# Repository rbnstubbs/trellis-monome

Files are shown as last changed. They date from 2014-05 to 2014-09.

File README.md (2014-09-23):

trellis-monome
==============
NOTE: Code is still not optimized for row/col commands! WIP

A monome clone using the Adafruit Trellis keypads

This project was largely based on the Arduinome by Owen Vallis & 
Jordan Hochenbaum: http://flipmu.com/work/arduinome/

Many thanks to Brian Crabtree and Kelli Cain as well as the rest of the monome community for creating supporting open source hardware/software: http://monome.org/

Robin Stubbs - robin.stubbs@uleth.ca

Click "Download ZIP" to get all files ------------------->

***
This program is free software; you can redistribute it and/or modify it under the terms of the GNU General Public License as published by the Free Software Foundation; either version 2 of the License, or (at your option) any later version.

This program is distributed in the hope that it will be useful, but WITHOUT ANY WARRANTY; without even the implied warranty of MERCHANTABILITY or FITNESS FOR A PARTICULAR PURPOSE.  See the GNU General Public License for more details.
***

NOTE: For now you will need Cycling '74 's Max (http://cycling74.com/downloads/), but only the runtime version (free!) in order to run the monomecereal.maxpat

INSTRUCTIONS:

1. Set up Trellis keypads according to adafruit: https://learn.adafruit.com/adafruit-trellis-diy-open-source-led-keypad?view=all

2. Place the Trellis_XY library by George Kuetemeyer in your libraries folder. Test your Trellis keypads using the test sketches - ensure that all LEDs are lighting up in order. If they are jumping from one keypad to another, change the order of addresses under trellis.begin()

3. Upload the latest trellis-monome firmware to your arduino. Start monomecereal.maxpat and choose your serial port (it will be the same as the one you used in the Arduino IDE). Click 'serial on' and 'osc on'

4. Open trellis-monome test.maxpatch and press your keys. Watch the buttons light up! If the right buttons are not lighting check the cable orientation in monomecereal.maxpat

5. You are done! download apps for the monome at http://monome.org/docs/app 

OPTIONAL: use the .stl files in the 3D folder and 3D print yourself an enclosure!

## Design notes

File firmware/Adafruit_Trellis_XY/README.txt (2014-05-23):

Adafruit_Trellis_XY

Copyright (C) 2014  George Kuetemeyer (gk@pobox.com)
   
This program is free software: you can redistribute it and/or modify
it under the terms of the GNU General Public License as published by
the Free Software Foundation, either version 3 of the License, or
(at your option) any later version.
   
This program is distributed in the hope that it will be useful,
but WITHOUT ANY WARRANTY; without even the implied warranty of
MERCHANTABILITY or FITNESS FOR A PARTICULAR PURPOSE. See the
  GNU General Public License for more details.
   
You should have received a copy of the GNU General Public License
along with this program. If not, see <http://www.gnu.org/licenses/>.

This is a library for the Adafruit Trellis PCB

Designed specifically to work with the Adafruit Trellis!
  ----> https://www.adafruit.com/products/1611
  ----> https://www.adafruit.com/products/1616
   
Version 1.2

---------------------------------------------------------------------------------
DESCRIPTION:

Adafruit_Trellis_XY is a library that can map one or more
Adafruit Trellises into a set of X/Y coordinates.

---------------------------------------------------------------------------------
INSTALLATION:

- Press "Download ZIP" button on GitHub page.
- Download Zip file and unzip it.
- Rename "Adafruit_Trellis_XY-master" folder name to "Adafruit_Trellis_XY"
- Copy the "Adafruit_Trellis_XY folder to your "libraries" directory.

In the Arduino IDE, create a new sketch and select fromn the menu bar
"Sketch->import Library->Adafruit_Trellis_XY. Be sure to place
#include <Adafruit_Trellis_XY.h> at the top of your sketch along with
other required libraries ( <Adafruit_Trellis.h>, etc.).

---------------------------------------------------------------------------------
CREATION:

Adafruit_Trellis_XY trellisXY = Adafruit_Trellis_XY();

---------------------------------------------------------------------------------
METHODS:

void begin (byte number_of_keys) // initialize trellisXY with total number of keys

void setOffsets (byte tile_number, byte x_offset, byte y_offset) // set X/Y offsets

void getTrellisX (byte trellisId) // get X coordinate for given trellis ID

void getTrellisY (byte trellisId) // get Y coordinate for given trellis ID

byte getTrellisId (byte xIn, byte yIn) // get Trellis ID for given X/Y coordinates
   
---------------------------------------------------------------------------------
MAPPING TRELLIS TILE XY OFFSETS
   
In order for this library to function correctly, it's important that you
work out required X and Y offsets for each tile. Here is an example using
four tiles in a square (8X8 buttons/leds):
   
  -----
  |2|3|  <---- tile layout for 8X8 matrix
  |0|1|  
  -----
   
Given that layout, this code will set up things correctly, assuming you've
defined an object trellisXY:
   
trellisXY.setOffsets(0, 0, 0);
trellisXY.setOffsets(1, 4, 0);
trellisXY.setOffsets(2, 0, 4);
trellisXY.setOffsets(3, 4, 4);

Be sure to reflect this layout when you set up trellis.begin. In the case of
a 4X4 matrix you will want to arrange your tile addresses to match this layout.

  trellis.begin(0x70, 0x71, 0x72, 0x73);

If you haven't physically arranged the tiles that way, then rearrange the entries
in the begin statment. Here is how I had to address my 4X4 matrix:

  trellis.begin(0x72, 0x73, 0x70, 0x71);
   
Here's another example:
   
  ---------
  |0|1|2|3|  <------ tile layout for 4X8 matrix
  ---------

trellisXY.setOffsets(0, 0, 0);
trellisXY.setOffsets(1, 4, 0);
trellisXY.setOffsets(2, 8, 0);
trellisXY.setOffsets(3, 12, 0);
   
Here is simplest example for one Trellis
   
  ---
  |0|  <------ tile layout for single Trellis
  ---
   
trellisXY.setOffsets(0, 0);

---------------------------------------------------------------------------------
SAMPLE CODE: 

//------------------------------------------------------------------------
#include <Wire.h>
#include <Adafruit_Trellis.h>
#include <Adafruit_Trellis_XY.h>

//------------------------------------------------------------------------
  This example shows reading buttons and setting/clearing buttons in a loop
  Also sending X/Y values to serial port.

  Up to 8 tiles can be used. This example uses 4 tiles

//------------------------------------------------------------------------
Adafruit_Trellis matrix0 = Adafruit_Trellis();
Adafruit_Trellis matrix1 = Adafruit_Trellis();
Adafruit_Trellis matrix2 = Adafruit_Trellis();
Adafruit_Trellis matrix3 = Adafruit_Trellis();

Adafruit_TrellisSet trellis =  Adafruit_TrellisSet(&matrix0, &matrix1, &matrix2, &matrix3);

#define NUMTRELLIS 4
#define NKEYS (NUMTRELLIS * 16)

Adafruit_Trellis_XY trellisXY = Adafruit_Trellis_XY();

#define INTPIN A2

//-----------------------------------------------------------
void setup() {
  Serial.begin(9600);
  Serial.println("Trellis X/Y Demo");

  // define number of keys
  trellisXY.begin(NKEYS);
  // set up x/y offsets
  trellisXY.setOffsets(0, 0, 0);
  trellisXY.setOffsets(1, 4, 0);
  trellisXY.setOffsets(2, 0, 4);
  trellisXY.setOffsets(3, 4, 4);
  
  // INT pin requires a pullup
  pinMode(INTPIN, INPUT);
  digitalWrite(INTPIN, HIGH);
  
  // Order is important here!! Start with tile address you want to
  // use as the first one, etc. Note that this will vary depending
  // on how you/ve set up addressing.
  trellis.begin(0x72, 0x73, 0x70, 0x71);

  // light LEDs 
  for (byte y = 0; y < 8; y++) {
    for (byte x = 0; x < 8; x++) {
      trellis.setLED(trellisXY.getTrellisId(x, y));
      trellis.writeDisplay();    
      delay(50);
    }
  }
  // then turn them off
  for (byte y = 0; y < 8; y++) {
    for (byte x = 0; x < 8; x++) {
      trellis.clrLED(trellisXY.getTrellisId(x, y));
      trellis.writeDisplay();    
      delay(50);
    }
  }
}

//------------------------------------------------------------------------
void loop() {
  delay(30);  
  // If a button was just pressed or released...
  if (trellis.readSwitches()) {
    // go through every button
    for (byte i=0; i < trellisXY.numKeys; i++) {
      byte xValue;
      byte yValue;
      byte xyTrellisID;
      // if it was pressed...
      if (trellis.justPressed(i)) {
        // print out X/Y values
        Serial.println("----------");
        // get x/y values
        xValue = trellisXY.getTrellisX(i);
        yValue = trellisXY.getTrellisY(i);
        Serial.print("x: "); Serial.println(xValue, DEC);
        Serial.print("y: "); Serial.println(yValue, DEC);
        // get Trellis ID from x/y values
        xyTrellisID = trellisXY.getTrellisId(xValue, yValue);
        Serial.print("xyTrellisID: "); Serial.println(xyTrellisID, DEC);
	// Alternate the LED
	if (trellis.isLED(i)) 
	  trellis.clrLED(i);
	else
	  trellis.setLED(i);
        }
     } 
  }
  trellis.writeDisplay();
}

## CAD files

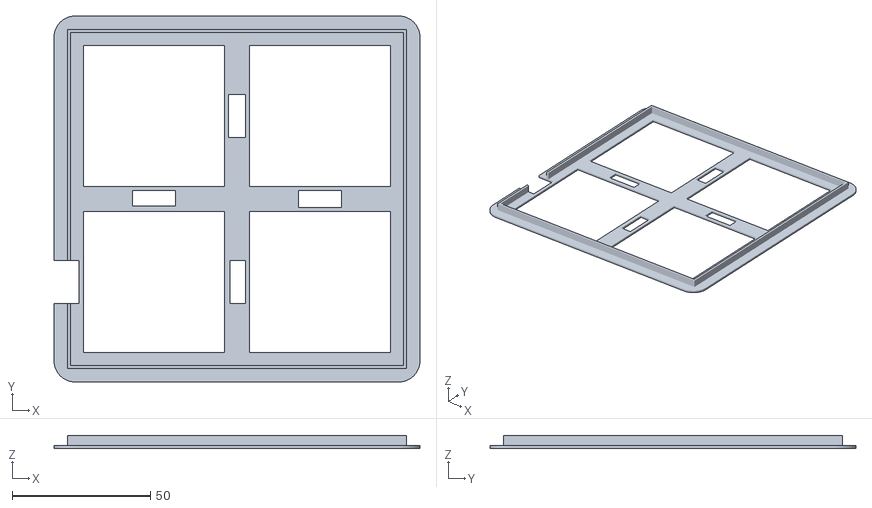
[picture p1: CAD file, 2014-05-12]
3D printable enclosure/pcb.stl
132.2 x 132.2 x 4.62

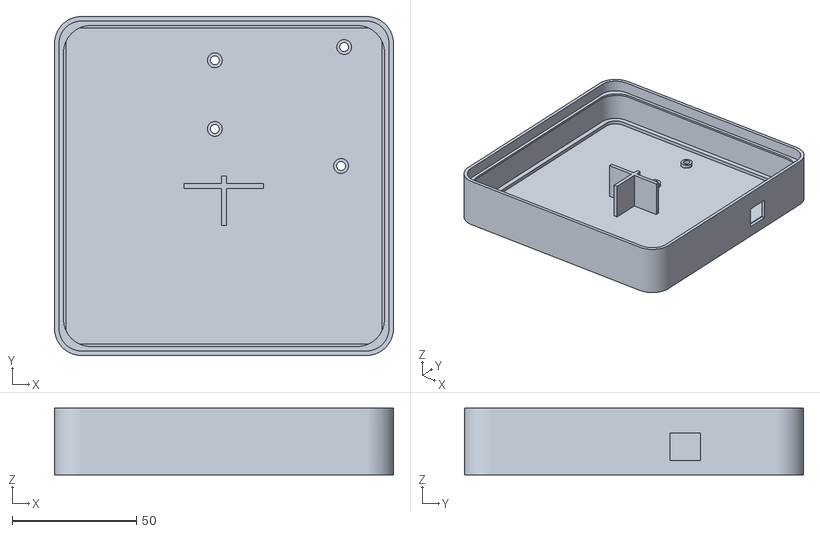
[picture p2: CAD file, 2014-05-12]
3D printable enclosure/base.stl
136.6 x 136.6 x 26.8

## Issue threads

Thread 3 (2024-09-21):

Trellis panels rotated 270º?

SoLongSidekick, 2024-09-21:
Took some doing but I'm finally in the final bits of getting this up and running. It's not compatible with Max 8 but will work with Max 7, if anyone else finds this in the future.

However the panels are rotated 270º from where they are supposed to be. For example, if pressing the buttons (in software) from the upper left corner across the top to the upper right corner what will actually light up is the bottom left corner of the upper left pad moving up vertically until reaching the upper left corner. Then when you reach what should be the upper center of the buttons the buttons in the lower left corner of the upper right pad activate moving upwards until it reaches the top. Kind of hard to explain, but if you tell the software to do what's shown on the left you instead get what's on the right:

X X X X X X X X       X 0 0 0 X 0 0 0
0 0 0 0 0 0 0 0         X 0 0 0 X 0 0 0
0 0 0 0 0 0 0 0         X 0 0 0 X 0 0 0
0 0 0 0 0 0 0 0         X 0 0 0 X 0 0 0
0 0 0 0 0 0 0 0         0 0 0 0 0 0 0 0
0 0 0 0 0 0 0 0         0 0 0 0 0 0 0 0
0 0 0 0 0 0 0 0         0 0 0 0 0 0 0 0
0 0 0 0 0 0 0 0         0 0 0 0 0 0 0 0

Is anyone aware of how to rotate the trellis pads themselves via firmware? I don't think physically rotating themselves inside the larger assembly will work.

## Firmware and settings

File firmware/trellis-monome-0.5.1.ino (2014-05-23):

 /*
RACS 40h translation
May 2014
https://github.com/rbnstubbs/trellis-monome

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
Designed to work with the Adafruit Trellis (four boards)
Uses Trellis XY Library by George Keutemeyer 
( https://github.com/Gkuetemeyer/Adafruit_Trellis_XY ) and an updated version 
of monomecereal.maxpat by James Drake ( http://monome.org/docs/doku.php?id=app:monomecereal ), 
but it will also work with monome's serialOSC if the USB chip is flashed, or
serialPyio, etc. A 3D printed enclosure was adapted from Adafruit's 
implementation. All files are on the git.

This sketch was largely based on the Arduinome clone by Owen Vallis & 
Jordan Hochenbaum: http://flipmu.com/work/arduinome/

http://monome.org/

Robin Stubbs
robin.stubbs@uleth.ca
*/


///Trellis and XY Init
 
    #include <Wire.h>
    #include <Adafruit_Trellis.h>
    #include <Adafruit_Trellis_XY.h>
    
    Adafruit_Trellis matrix0 = Adafruit_Trellis();
    Adafruit_Trellis matrix1 = Adafruit_Trellis();
    Adafruit_Trellis matrix2 = Adafruit_Trellis();
    Adafruit_Trellis matrix3 = Adafruit_Trellis();

    Adafruit_TrellisSet trellis =  Adafruit_TrellisSet(&matrix0, &matrix1, &matrix2, &matrix3);

    #define NUMTRELLIS 4
    #define NKEYS (NUMTRELLIS * 16)

    Adafruit_Trellis_XY trellisXY = Adafruit_Trellis_XY();

    #define INTPIN A3
        

    /// SETUP    
void setup() {
      Serial.begin(115200);
//      Serial.println("racs arduinome");
      
      // XY Init:
      // define number of keys
      trellisXY.begin(NKEYS);
      // set up x/y offsets
      trellisXY.setOffsets(0, 0, 0);
      trellisXY.setOffsets(1, 4, 0);
      trellisXY.setOffsets(2, 0, 4);
      trellisXY.setOffsets(3, 4, 4);
      
      // INT pin requires a pullup
      pinMode(INTPIN, INPUT);
      digitalWrite(INTPIN, HIGH);
     
      // order is important here!! Start with tile address you want to
      // use as the first one, etc.
      trellis.begin(0x71, 0x70, 0x72, 0x73);

  /// XY init seq SET
   setRows();
 
  /// INTERRUPT INIT - NOTE: works with ATMega 128 based boards ONLY, 
  // can be adapted for others
  // Set up 8-bit counter 2, output compare switched off,
  // normal waveform generation (whatever that might mean)
//  TCCR2A = 0;
  // set counter to be clocked at 16Mhz/8 = 2Mhz
//  TCCR2B = 1<<CS21;

  // set the interrupt mask so that we get an interrupt
  // on timer 2 overflow, i.e. after 256 clock cycles.
  // The timer 2 interrupt routine will execute every
  // 128 uS.
//  TIMSK2 = 1<<TOIE2;

  // NOTE: In my efforts to try to get this
  // code to work reliably at 115200 baud
  // I went about disabling unused timers that
  // are set up by the Arduino framework.
  // The framework sets up both timer 2 and 
  // timer 1.  We use timer 2 to drive the
  // serial reading interrupt, so we can only
  // disable timer1 and its interrupt.

  // REALLY IMPORTANT NOTE - IF YOU WANT TO USE
  // ANALOGWRITE

  // Disabling timer 1 will switch off the timer
  // used for PWM, which underlies analogWrite.
  // If you want to use analogWrite, remove
  // the lines below.

  // DISABLE PWM COUNTER
  TCCR1B &= ~(1 << CS12);
  TCCR1B &= ~(1 << CS11);
  TCCR1B &= ~(1 << CS10);  
  // END DISABLE PWM COUNTER

  // Also, disable the interrupts on timer 0
  // REALLY IMPORTANT NOTE IF YOU WANT TO USE
  // DELAY remove this line
//   TIMSK0 &= ~(1 << TOIE0);
   
   /// XY init seq CLR - after INT INIT to ensure proper startup
    clearRows();
//    Serial.println("testing 1 2");
}


///////////////////////////////////////////////////////////////////////
// Global variables 

byte byte0, byte1, row = 0;                      // storage for incoming serial data

boolean WaitingCommand = true;          // true when we expect the next serial byte to be an address value, false otherwise
int command =  0;                       // garbage int to hold address of function

byte state = 0x00;                      // garbage byte to hold state value
byte x = 0x00;                          // garbage byte to hold x position
byte y = 0x00;                          // garbage byte to hold y position
byte z = 0x00;                          // garbage byte to iterate over buttons




// The following variables are used to store flags that indicate whether we have received a given message,
// the value of the data in that message.  e.g. IntensityChange = 0 == no intensity change message received,
// IntensityChange = 1 == an intensity change message has been received, and it's value will be in IntensityVal
// The code that eventually acts upon the incoming message will reset the 'Change' variable to 0 once the 
// message has been handled.            

int ShutdownModeChange = 0;            
boolean ShutdownModeVal = false;

int i = 0;                              // temporary variable for looping etc.
int id = 0;                             // temporary storage for incoming message ID
int curInt = 15;
int prevInt = 15;

unsigned long interval = 12;  // debounce time CAN BE ALTERED
unsigned long previousMillis=0; // millis() returns an unsigned long.

// These variables are used to handle the tilt messages, and store which ports are currently enabled,
// and which are not.
int tiltEnable = 0;
byte tiltNum;
byte tiltState;
const int xPin = A3;                  // x-axis of the accelerometer - CHANGE these as necessary
const int yPin = A2;                  // y-axis
const int zPin = A1;                  // z-axis (only on 3-axis models)

byte ADCnum;
byte ADCstate;
byte ADCEnableState[4];

///////////////////////////////////////////////
/// LED Functions
void setRows() {
      for (uint8_t y=0; y<8; y++) {
          for (uint8_t x=0; x<8; x++) {
                trellis.setLED(trellisXY.getTrellisId(x, y));
                trellis.writeDisplay();
     }
  }
}

void clearRows() {
      for (uint8_t x=0; x<8; x++) {
          for (uint8_t y=0; y<8; y++) {
              trellis.clrLED(trellisXY.getTrellisId(x, y));
              trellis.writeDisplay();
          }
      }
  }

////////////////////////////////////////////////
/// RACS - button states

    void checkButtons () {
      if ((unsigned long)(millis() - previousMillis) >= interval) {
        byte xVal;
        byte yVal;
                
        if (trellis.readSwitches()) {

          for (uint8_t i=0; i<NKEYS; i++) {

            if (trellis.justPressed(i)) {
               xVal = trellisXY.getTrellisX(i);
               yVal = trellisXY.getTrellisY(i);     
               Serial.write((0 << 4) | (1 & 15)); 
               Serial.write((yVal << 4) | (xVal & 15));              
            }
            if (trellis.justReleased(i)) {
               xVal = trellisXY.getTrellisX(i);
               yVal = trellisXY.getTrellisY(i);
               Serial.write((0 << 4) | (0 & 15)); 
               Serial.write((yVal << 4) | (xVal & 15));
       	   }
          }
        }
         previousMillis = millis();
      }
    }

///////////////////////////////////////////////
/// RACS JUST Check Serial now (pretty much straight out of the Arduinome)
/// This should eventually be re-implemented as an interrupt, it seems to lag a little

void checkSerial() {
    
    do {
      if (Serial.available()) {
        if (WaitingCommand) {          // command is the first byte of the two byte command
          byte0 = Serial.read();
          command = byte0 >> 4;
          WaitingCommand = false;
        }

           if(Serial.available()) { // command outside range so must be an error
              WaitingCommand = true; // the next byte is the first byte of the next command
              byte1 = Serial.read(); // read the second byte of this command
 
              switch(command) {
 
                case 2: // LED command
                state = byte0 & 0x0f; // is the command for on or off
                x = ((byte1 >> 4) & 0x07); // mask so we don't go over the 8 by 8 grid
                y = ((byte1 & 15) & 0x07);
 
                  if (state == 0) {
                      trellis.clrLED(trellisXY.getTrellisId(y, x)); //offLED(x, y);
                 }
                   else {
                   trellis.setLED(trellisXY.getTrellisId(y, x)); //onLED(x, y);
                   }
                  break;
 
                case 3: // led intensity command
                  curInt = (byte1 & 0x0f);
                break;
                 
                case 4: // led test command
                  if( (byte1 & 1) == 0) {
                    clearRows();
                   }
                  else {
                    setRows();
                   }
                break;
                
                case 5: // enable tilt command
                  state = byte1 & 0x0F;
                  ADCEnableState[(byte1 >> 4)&0x03] = state;
                break;
                
                case 6: // shutdown command - not sure what the monome is expected to do here
                  ShutdownModeChange = true;
                  ShutdownModeVal = byte1 & 15;
                break;
                
                case 7: // led row command
                  y = byte0 & 0x07; // mask this value so we don't write to an invalid address.
                  x = 0;
                  for(byte i = 0x1; i != 0x0; i <<= 1 ) {
                    if( (i & byte1) != 0) {
                    trellis.setLED(trellisXY.getTrellisId(y, x)); //onLED(x, y);
                   }
                  else {
                       trellis.clrLED(trellisXY.getTrellisId(y, x)); // offLED(x, y);
                  }
                  x++;
                }
                break;
 
                case 8: // colomn command
                  x = byte0 & 0x07; // mask this value so we don't write to an invalid address.
                  y = 0;
                  for(byte i = 0x1; i != 0x0; i <<= 1 ) {
                    if( (i & byte1) != 0) {
                      trellis.setLED(trellisXY.getTrellisId(y, x)); //onLED(x, y);
                    }
                    else {
                      trellis.clrLED(trellisXY.getTrellisId(y, x)); //offLED(x, y);
                    }
                  y++;
                }
                break;
                
               } // end switch(command)
              } // end of else in if(WaitingCommand)
             } // end of if(Serial.available();
            } // end of do
           while (Serial.available() > 16); // keep on going if we have a lot of commands stacked up
          }

/// ADC commands
void sendADC(int port, int value) {
  Serial.write((1 << 4) | ((port << 2) & 0x0C) | ((value >> 8) & 0x03));
  Serial.write(value & 0xFF);
}

int current[4]; 
int previous[4]; 
int tolerance = 7;

void checkADCs() {

  for (int adcCounter = 0; adcCounter < 4; adcCounter++)
  {

    if (ADCEnableState[adcCounter] != 0)
    {
      current[adcCounter] = analogRead(adcCounter);

      if (abs(previous[adcCounter]-current[adcCounter]) > tolerance)
      {
        previous[adcCounter] = current[adcCounter];
        sendADC(adcCounter,current[adcCounter]);
      }
    }
  }
}

///// /TILT - not yet
//void sendTilt(int x, int y, int z) {
//      Serial.write((8 << 4) | ((1 << 2) & 0x0C) | ((x >> 8) & 0x03));
//      Serial.write(x & 0xFF);
//      Serial.write(y & 0xFF);
//      Serial.write(z & 0xFF); 
////        byte xyz = (
////        Serial.write(nxyz, sizeof(nxyz))
//}
//  
//int cur[3];  // val[3]
//int prev[3]; 
//int tol = 7;
//int aX;
//int aY;
//int aZ;
//
//void checkTilt() {
//    if (tiltEnable != 0) {
//      aX = analogRead(xPin);
//      aY = analogRead(yPin);
//      aZ = analogRead(zPin);
//      sendTilt(aX,aY,aZ);
//      }
//}


/// RACS - Send it 
void loop() {
  checkSerial();
  checkButtons();
  trellis.writeDisplay();
//  checkTilt();
  checkADCs();
  
  /// Intensities - sets ALL LEDs only until the Trellis lib is edited
  if (curInt != prevInt) {
    trellis.setBrightness(curInt); 
    curInt = prevInt;
  }
 }
 
//eof
